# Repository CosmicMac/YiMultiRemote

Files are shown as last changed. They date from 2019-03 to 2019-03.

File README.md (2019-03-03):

# Multi Yi cameras remote

**Trigger a couple of YI 4K+ Action Camera (aka "poor man's VR rig") with an ESP8266.**

Video sync is frame accurate (4k@60fps mode) but photo sync is random, from quite good to useless.\
I suspect the auto shutter mode to be the culprit of missync but didn't tried with manual settings
as I'm not too much interested in still pictures (at least using these cameras).

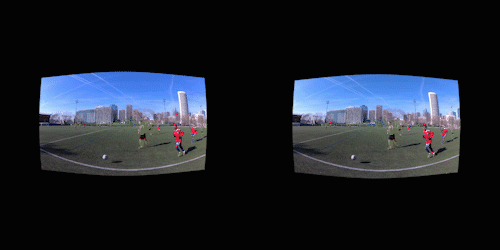
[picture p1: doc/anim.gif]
Anim
\
*People running after a ball make good sync test.*

## Prerequisites

To make your Yi 4K+ action cameras run in station mode, create a folder named `Wi-Fi.DEBUG` in
the root of each SD card.\
Then inside that folder create a file named `start.sh` and edit that file with your favorite text
editor (make sure to set the line endings to UNIX).

For the left camera SD card, your file should look like this:
````
#!/bin/sh
# Change the MAC adress according to your left camera
/usr/local/share/network/start.sh WIFI_MODE=sta STA_SSID=YiMultiRemote STA_PASSWD=YMR12345 STA_FREQ=0 STA_NAME=yi_cam_left STA_SCAN=1 STA_IP=192.168.0.10 CHIP_TYPE=43340 WIFI_MAC=58:70:C6:XX:XX:XX
````

For the right camera SD card, your file should look like this:
````
#!/bin/sh
# Change the MAC adress according to your right camera
/usr/local/share/network/start.sh WIFI_MODE=sta STA_SSID=YiMultiRemote STA_PASSWD=YMR12345 STA_FREQ=0 STA_NAME=yi_cam_right STA_SCAN=1 STA_IP=192.168.0.11 CHIP_TYPE=43340 WIFI_MAC=58:70:C6:YY:YY:YY
````

## Hardware
- ESP8266 - Wemos D1 module
- Momentary switch
- LED
- 68 ohms resistor (actual value depends on the LED model)
- Buzzer

### Wiring
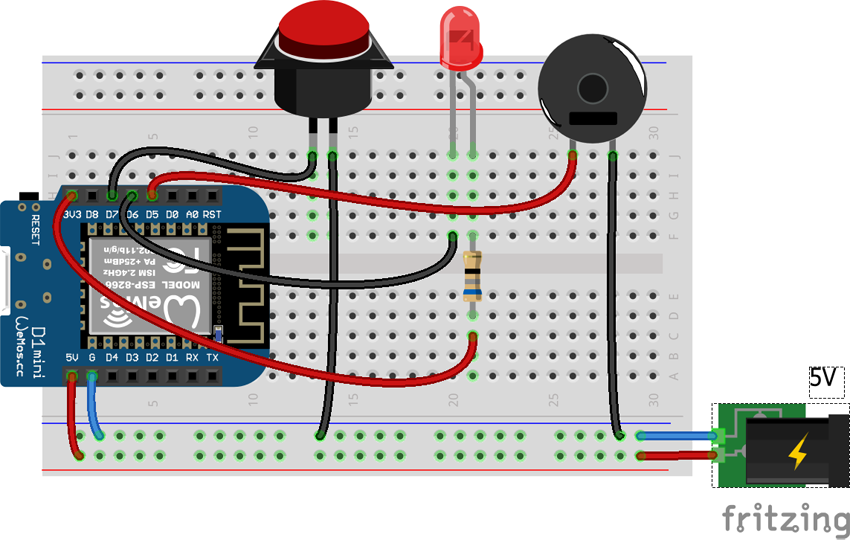
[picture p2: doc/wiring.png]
Wiring


### Enclosure
I found this [Hama foldable flash bracket](https://www.hama.com/00006831) quite handy
when coupled with a lipstick-sized battery pack.\
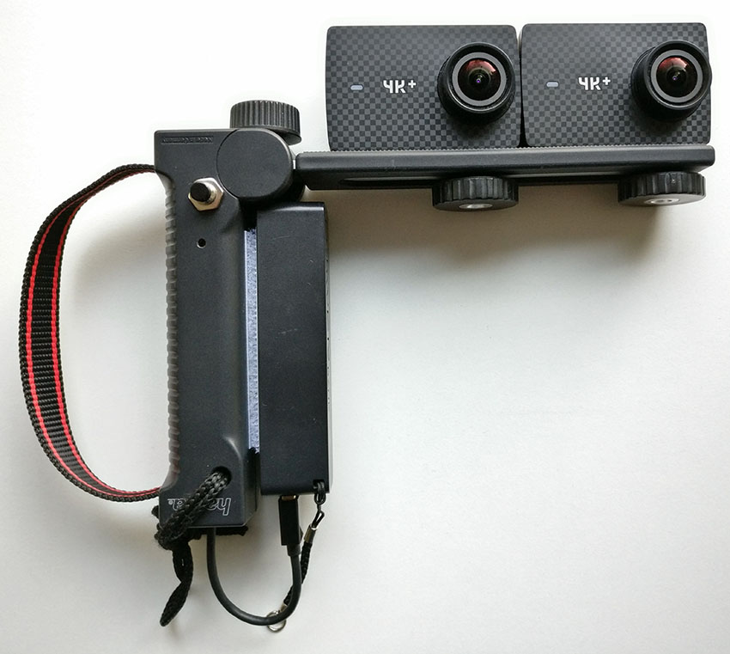
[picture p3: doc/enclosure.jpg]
Enclosure

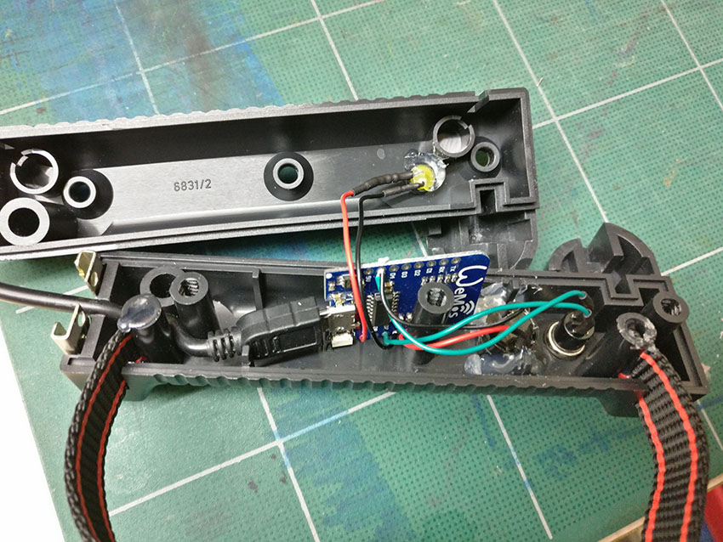
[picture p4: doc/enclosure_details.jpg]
Enclosure details


## Software
Multi Yi cameras remote was tested with version 2.4.2 of the Arduino libraries for ESP8266.

### External libraries
- https://github.com/bblanchon/ArduinoJson
- https://github.com/mathertel/OneButton
- https://github.com/me-no-dev/ESPAsyncWebServer

*See README of each library for specific installation instructions.*

## Miscellaneous

### Caveat
The following start-up sequence must be observed: power on the ESP8266, then the left camera,
finally the right camera.\
Reconnection is not supported in this version: if a camera disconnects, all devices must
be switched off and above sequence restarted from the beginning.

### Commands
- Button click: either captures photo or toggle video recording
- Button double click: alternates between photo and video mode
- Button long press: restarts ESP8266

As an alternative to the button, you can connect your smartphone to the AP and use the web interface.

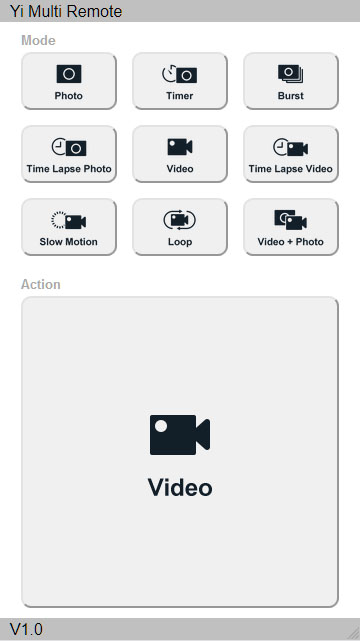
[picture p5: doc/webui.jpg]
Web ui


### Useful links
- https://dashcamtalk.com/forum/forums/yi-4k-action-camera.224
- https://github.com/irungentoo/Xiaomi_Yi_4k_Camera
- https://github.com/jnordberg/yichan (also [this thread](https://github.com/jnordberg/yichan/issues/1))
- https://github.com/kongzii/xiaomi-yi
- https://github.com/NikolayRag/Yi4kAPI 

### Disclaimer
Even if I try to improve myself, my C++ skills are very limited: I do programming like a Lego player,
essentially by assembling bricks made by real programmers.\
You've been warned...

For a real disclaimer, see the MIT license.

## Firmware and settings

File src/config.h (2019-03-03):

#ifndef YMR_CONFIG_H
#define YMR_CONFIG_H

/**
 * AP
 */
#define AP_IP               IPAddress(192, 168, 0, 1)
#define AP_SSID             "YiMultiRemote"
#define AP_PWD              "YMR12345"

/**
 * CLIENTS
 */
#define CLIENT1_IP          IPAddress(192, 168, 0, 10)
#define CLIENT2_IP          IPAddress(192, 168, 0, 11)
#define CLIENT_PORT         7878

/**
 * ONEBUTTON
 */
#define BTN_PIN             D7    // GPIO13
#define BTN_CLICK_DELAY_MS  500   // Number of millisec before a click is detected (triggers action)
#define BTN_LPRESS_DELAY_MS 1000  // Number of millisec before a long press is detected (triggers restart)

/**
 * LED
 */
#define LED_PIN             D6    // GPIO12

/**
 * BUZZER
 */
#define BUZZER_PIN          D5    // GPIO14
#define BUZZER_FREQUENCY    3000
#define BUZZER_DURATION     100

/**
 * CAMERA MODES
 */
#define DEFAULT_VIDEO_MODE  "record"
#define DEFAULT_PHOTO_MODE  "precise quality"

/**
 * DNS SERVER
 */
#define DNS_PORT            53

/**
 * BEEP ON VIDEO
 * Beep a few seconds after video start, and a few secondes before video stop
 * May be helpful to control and adjust sync between left and right camera
 */
#define BEEP_ON_VIDEO       true

/**
 * YI MESSAGES IDS
 */
#define YI_MSG_CAPTURE_PHOTO   769
#define YI_MSG_START_VIDEO_REC 513
#define YI_MSG_STOP_VIDEO_REC  514

#endif //YMR_CONFIG_H

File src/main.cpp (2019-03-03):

/**
 * Yi Multi Remote
 * 
 * Trigger a couple of YI 4K+ Action Camera
 */

#include <Arduino.h>
#include <ESP8266WiFi.h>
#include <ArduinoJson.h>
#include <OneButton.h>
#include <ESPAsyncWebServer.h>
#include <DNSServer.h>
#include <FS.h>
#include "main.h"
#include "config.h"

OneButton button(BTN_PIN, true);
DNSServer dnsServer;
AsyncWebServer webServer(80);
WiFiClient client1;
WiFiClient client2;

uint8_t token1;
uint8_t token2;

bool videoMode = true;          // true when in video mode, false when in photo mode
bool videoRec = false;          // true when video recording in progress
bool stationsConnected = false; // true when both cameras are connected to AP
bool clientsConnected = false;  // true when both cameras are connected to server
bool actionTriggered = false;   // Indicates if action has been triggered by the web server


/**
 * SETUP
 */
void setup() {
    Serial.begin(115200);
    Serial.println();

    pinMode(LED_PIN, OUTPUT);
    digitalWrite(LED_PIN, HIGH);


    /**
     * START WIFI ACCESS POINT
     */

    WiFi.softAPConfig(AP_IP, AP_IP, IPAddress(255, 255, 255, 0));
    if (!WiFi.softAP(AP_SSID, AP_PWD, 6)) {
        Serial.println(F("Unable to start Access Point"));
        restartESP(10000);
    }

    Serial.printf_P(PSTR("Access point \"%s\" started with IP "), AP_SSID);
    Serial.println(WiFi.softAPIP());


    /**
     * DNS SERVER SETUP
     */

    dnsServer.setErrorReplyCode(DNSReplyCode::NoError);
    dnsServer.start(DNS_PORT, "*", AP_IP);


    /**
     * WEB SERVER SETUP
     */

    if (!SPIFFS.begin()) {
        Serial.println("SPIFFS begin failed");
        restartESP(10000);
    }

    webServer.on("/action", HTTP_GET, [](AsyncWebServerRequest *request) {
        Serial.println(F("webServer.on /action"));
        if (clientsConnected) {
            // This is a workaround as we can't use yield (or any
            // function that uses it) inside the callback
            actionTriggered = true;
        }
        request->send(204);
    });

    webServer.on("/mode", HTTP_GET, [](AsyncWebServerRequest *request) {
        Serial.println(F("webServer.on /mode"));
        if (clientsConnected) {
            AsyncWebParameter *type = request->getParam("type");
            AsyncWebParameter *param = request->getParam("param");
            setMode(type->value().c_str(), param->value().c_str());
        }
        request->send(204);
    });

    webServer.serveStatic("/", SPIFFS, "/").setDefaultFile("index.html");

    webServer.onNotFound([](AsyncWebServerRequest *request) {
        request->send(SPIFFS, "/index.html");
    });

    webServer.begin();
    Serial.println("HTTP server started");


    /**
     * ONEBUTTON SETUP
     */

    button.setClickTicks(BTN_CLICK_DELAY_MS);
    button.setPressTicks(BTN_LPRESS_DELAY_MS);

    // Either capture photo or toggle video recording on click
    button.attachClick([]() {
        Serial.println(F("Button click!"));
        if (clientsConnected) {
            action();
        }
    });

    // Alternate between photo and video mode on double click
    button.attachDoubleClick([]() {
        Serial.println(F("Button double click!"));
        if (clientsConnected) {
            videoMode = !videoMode;
            if (videoMode) {
                setMode("rec_mode", DEFAULT_VIDEO_MODE);
            } else {
                setMode("capture_mode", DEFAULT_PHOTO_MODE);
            }
        }
    });

    // Restart ESP on long press
    button.attachLongPressStart([]() {
        Serial.println(F("Button long press!"));
        restartESP();
    });
}


/**
 * LOOP
 */
void loop() {

    if (!stationsConnected) {

        // Yi cameras are supposed to be the first 2 devices connected to the AP
        // Remember not to connect your smartphone until the initialization sequence has ended
        // Reconnection is not supported in this version : if a camera disconnects, all devices
        // must be switched off and the initialization sequence restarted from the beginning.

        if (WiFi.softAPgetStationNum() == 2) {
            stationsConnected = true;
            Serial.println(F("All stations connected to AP"));

            // Turns the LED on to signal both cameras are connected
            digitalWrite(LED_PIN, LOW);

            // Client 1 initialization
            if (!client1.connect(CLIENT1_IP, CLIENT_PORT)) {
                Serial.println(F("Unable to connect client1!"));
                restartESP(10000);
            }

            Serial.println(F("Client1 connected!"));
            getToken(client1, token1);

            // Client 2 initialization
            if (!client2.connect(CLIENT2_IP, CLIENT_PORT)) {
                Serial.println(F("Unable to connect client2!"));
                restartESP(10000);
            }

            Serial.println(F("Client2 connected!"));
            getToken(client2, token2);

            // Both cameras are fully initialized \o/
            clientsConnected = true;

            // Turns them to video mode
            setMode("rec_mode", DEFAULT_VIDEO_MODE);
            videoMode = true;

            // Turns the LED off and beep to signal end of initialization sequence
            // Now you are free to connect your smartphone to the AP
            digitalWrite(LED_PIN, HIGH);
            tone(BUZZER_PIN, BUZZER_FREQUENCY, BUZZER_DURATION);
        }
    }

    // OneButton handler
    button.tick();

    // DNS handler
    dnsServer.processNextRequest();

    // Action handler (triggered in web server callback)
    if (actionTriggered) {
        action();
        actionTriggered = false;
    }
}


/**
 * Get token
 */
void getToken(WiFiClient &client, uint8_t &token) {

    Serial.println(F("Sending token request..."));

    client.println(F(R"({"msg_id":257,"token":0 })"));

    // Get response
    // !FIXME Handle mixed responses
    // {"rval":0,"msg_id":257,"param":1,"model":"Z18","rtsp":"rtsp://192.168.42.1/live"}{"msg_id":7,"type":"battery","param":"75"}

    unsigned long timeout = millis();
    while (client.available() == 0) {
        if (millis() - timeout > 20000) {
            Serial.println(F(">>> Client Timeout !"));
            return;
        }
        yield();
    }

    String response = client.readStringUntil('\r');
    Serial.printf_P(PSTR("Client response: %s\n"), response.c_str());

    StaticJsonBuffer<512> jsonInBuffer;
    JsonObject &json = jsonInBuffer.parseObject(response);

    if (!json.success()) {
        Serial.println(F("Unable to parse response"));
        return;
    }

    if (json.containsKey(F("param"))) {
        token = json["param"].as<uint8_t>();
        Serial.printf_P(PSTR("Token: %d\n"), token);
    }
}


/**
 * Capture photo
 */
void capturePhoto() {
    fireYiMessage(YI_MSG_CAPTURE_PHOTO);
}


/**
 * Toggle video recording
 * 
 * Video recording is toggled on or off depending on videoRec flag
 */
void toggleVideo() {
    if (videoRec) {

        if (BEEP_ON_VIDEO) {
            // First, beep...
            tone(BUZZER_PIN, BUZZER_FREQUENCY, BUZZER_DURATION);
            unsigned long m = millis();
            while (millis() - m < 1000) {
                yield();
            }
        }

        // ...then stop video
        fireYiMessage(YI_MSG_STOP_VIDEO_REC);

    } else {

        // First, start video...
        fireYiMessage(YI_MSG_START_VIDEO_REC);

        if (BEEP_ON_VIDEO) {
            // ...then beep
            unsigned long m = millis();
            while (millis() - m < 2000) {
                yield();
            }
            tone(BUZZER_PIN, BUZZER_FREQUENCY, BUZZER_DURATION);
        }
        
    }
    videoRec = !videoRec;
}


/**
 * Send message to Yi, without considering the response
 * 
 * uint16_t id Message id
 */
void fireYiMessage(uint16_t id) {

    char msg[100];
    const char *format = R"({"token":%d,"msg_id":%d})";

    snprintf(msg, sizeof(msg), format, token1, id);
    client1.print(msg);

    snprintf(msg, sizeof(msg), format, token2, id);
    client2.print(msg);

    // Trying to improve camera sync by finalizing the message at the same time
    client1.println();
    client2.println();
}


/**
 * Either trigger photo capture or start/stop video recording
 */
void action() {
    if (videoMode) {
        toggleVideo();
    } else {
        capturePhoto();
    }
}


/**
 * Set camera mode
 *
 * @param type
 * @param param
 */
void setMode(const char *type, const char *param) {

    char msg[100];
    const char *format = R"({"token":%d,"msg_id":2,"type":"%s","param":"%s"})";

    snprintf(msg, sizeof(msg), format, token1, type, param);
    client1.println(msg);

    snprintf(msg, sizeof(msg), format, token2, type, param);
    client2.println(msg);

    videoMode = (strcmp(type, "rec_mode") == 0);
}


/**
 * Restarts ESP after delayMs milliseconds
 *
 * @param delayMs
 */
void restartESP(uint16_t delayMs) {

    uint8_t i;
    for (i = 0; i < 3; i++) {
        tone(BUZZER_PIN, BUZZER_FREQUENCY, BUZZER_DURATION);
        delay(100);
    }

    unsigned long m = millis();
    while (true) {
        if (millis() - m > delayMs)
            ESP.restart();
        yield();
    }
}
